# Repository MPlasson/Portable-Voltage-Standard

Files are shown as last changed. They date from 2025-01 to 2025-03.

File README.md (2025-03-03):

# Portable Voltage Standard
A portable voltage reference module, based on the REF7050 chip from Ti.

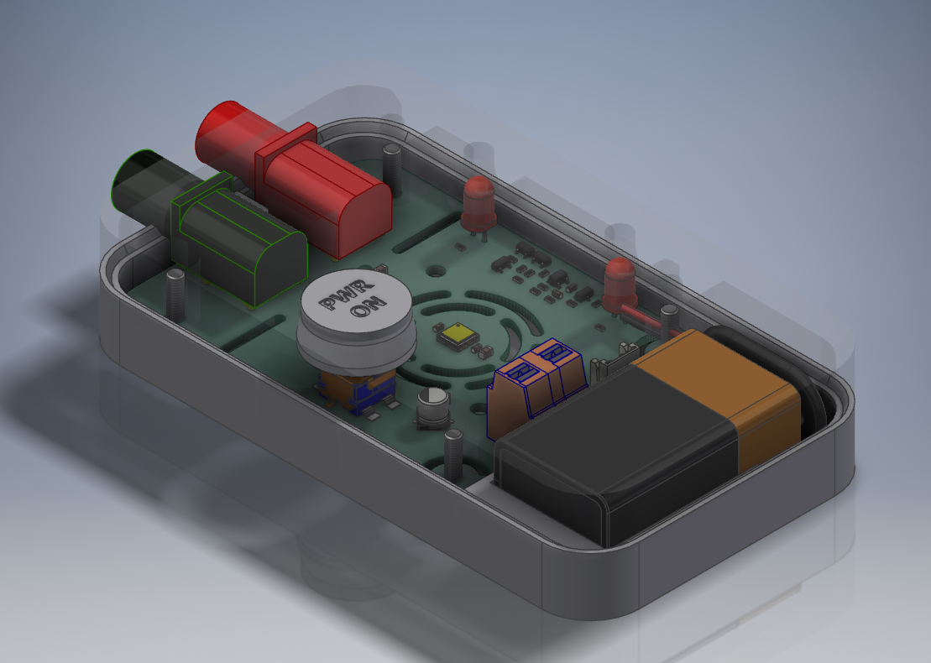
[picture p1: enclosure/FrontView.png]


## Features

- Stable 5V output with high accuracy (< 0.025%)
- Very low temperature coefficient (< 2ppm/°C)
- Battery powered for lowest noise & portability
- Power Good LED indicator
- Low Battery LED indicator

## Tests status

Link to test report: [TestReport](tests/index.md)

- [x] Initial bringup
- [ ] Line regulation
- [ ] Load regulation
- [x] Current consumption
- [ ] Low battery LED trigger voltage
- [x] Ambient temperature accuracy
- [x] Temperature drift [20°C - 50°C]
- [ ] Output stability (100h minimum)

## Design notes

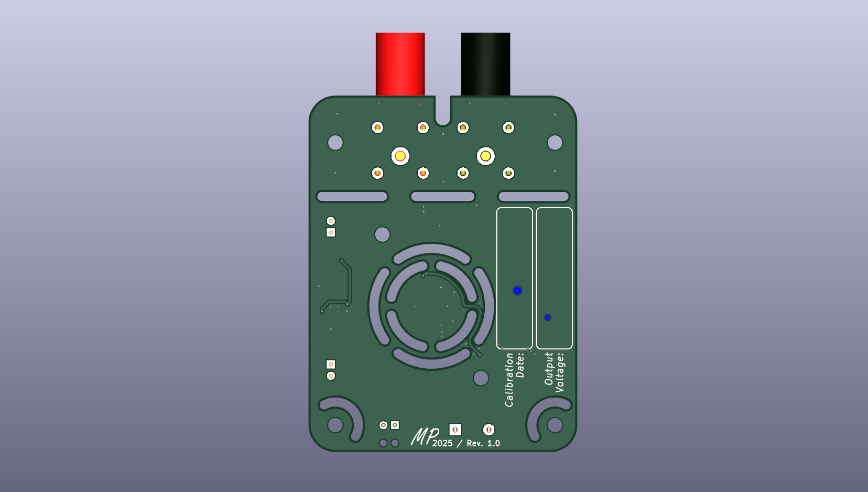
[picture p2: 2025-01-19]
electronics/mainboard/IMG/PortableVoltageStandard_BottomView.png

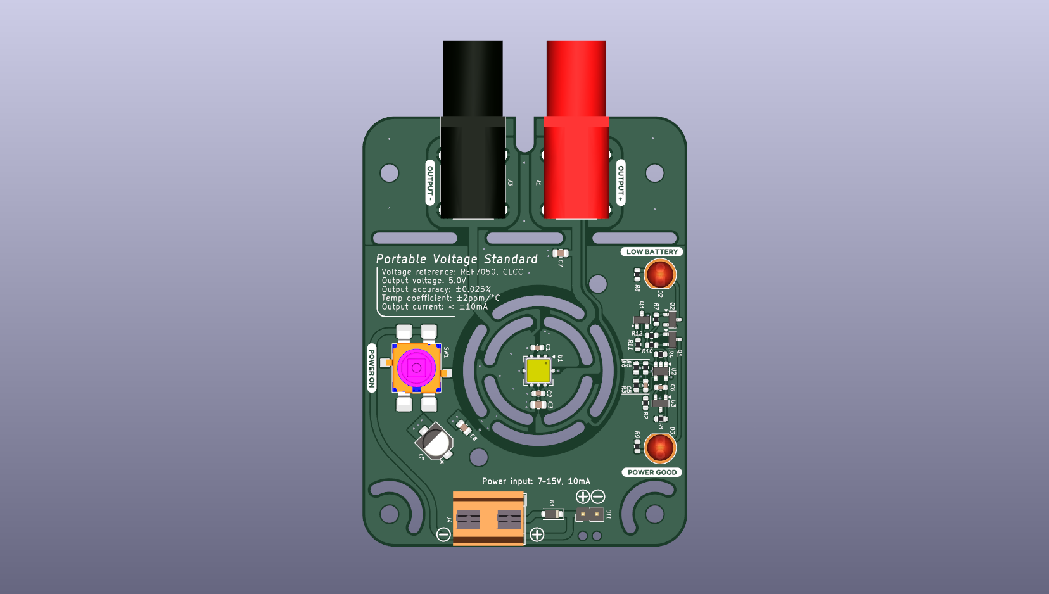
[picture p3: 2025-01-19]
electronics/mainboard/IMG/PortableVoltageStandard_topView.png

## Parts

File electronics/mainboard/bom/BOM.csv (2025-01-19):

Reference | Value | Datasheet | Footprint | Qty | DNP | LCSC
BT1 | 9V_Battery | ~ | Connector_JST:JST_EH_B2B-EH-A_1x02_P2.50mm_Vertical | 1 |  | C3018737
C1,C2,C5,C6 | 100nF | ~ | Capacitor_SMD:C_0603_1608Metric | 4 |  | C14663
C3,C7 | 22uF | ~ | Capacitor_SMD:C_0805_2012Metric | 2 |  | C602037
C4 | 10uF | ~ | Capacitor_SMD:CP_Elec_5x5.3 | 1 |  | C365682
C8 | 1uF | ~ | Capacitor_SMD:C_0805_2012Metric | 1 |  | C28323
D1 | K14 | ~ | Diode_SMD:D_SOD-123F | 1 |  | C908662
D2 | LOW_VOLTAGE | ~ | LED_THT:LED_D5.0mm | 1 |  | C7470717
D3 | POWER_GOOD | ~ | LED_THT:LED_D5.0mm | 1 |  | C7433083
J1 | OUTF | ~ | KICAD_GENERAL_LIBRARY:banana_socket_24.245.1_Amass_rouge | 1 |  | C7437326
J3 | GND | ~ | KICAD_GENERAL_LIBRARY:banana_socket_24.245.2_Amass_noire | 1 |  | C7437327
J4 | AUX_POWER | ~ | TerminalBlock_MetzConnect:TerminalBlock_MetzConnect_Type171_RT13702HBWC_1x02_P7.50mm_Horizontal | 1
Q1,Q2 | AP2302B | https://www.lcsc.com/datasheet/lcsc_datasheet_2411201841_ALLPOWER-ShenZhen-Quan-Li-Semiconductor-AP2302B_C406812.pdf | Package_TO_SOT_SMD:SOT-23 | 2 |  | C406812
Q3 | AP2301B | https://www.lcsc.com/datasheet/lcsc_datasheet_2411201843_ALLPOWER-ShenZhen-Quan-Li-Semiconductor-AP2301B_C2763847.pdf | Package_TO_SOT_SMD:SOT-23 | 1 |  | C2763847
R1 | 33k | ~ | Resistor_SMD:R_0603_1608Metric | 1 |  | C126359
R2 | 470k | ~ | Resistor_SMD:R_0603_1608Metric | 1 |  | C114622
R3 | 100k | ~ | Resistor_SMD:R_0603_1608Metric | 1 |  | C14675
R4,R10 | 1Meg | ~ | Resistor_SMD:R_0603_1608Metric | 2 |  | C105578
R5,R6 | 300k | ~ | Resistor_SMD:R_0603_1608Metric | 2 |  | C114667
R7,R11,R12 | 100 | ~ | Resistor_SMD:R_0603_1608Metric | 3 |  | C105588
R8,R9 | 1k | ~ | Resistor_SMD:R_0603_1608Metric | 2 |  | C22548
SW1 | SW_Push_SPDT | ~ | KICAD_GENERAL_LIBRARY:SPEF210200 | 1 |  | C278409
U1 | REF7050 | https://www.lcsc.com/datasheet/lcsc_datasheet_2309251242_Texas-Instruments-REF7050QFKHT_C6760318.pdf | Package_LCC:Analog_LCC-8_5x5mm_P1.27mm | 1 |  | C6760318
U2 | NCS333 | https://www.onsemi.com/pdf/datasheet/ncs333-d.pdf | Package_TO_SOT_SMD:SOT-23-5 | 1 |  | C74336
U3 | LM4040DBZ-2.5 | http://www.ti.com/lit/ds/symlink/lm4040-n.pdf | Package_TO_SOT_SMD:SOT-23 | 1 |  | C2156989

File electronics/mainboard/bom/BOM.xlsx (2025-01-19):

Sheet: BOM (2)
Reference | Value | Datasheet | Footprint | Qty | DNP | LCSC
BT1 | 9V_Battery | ~ | Connector_JST:JST_EH_B2B-EH-A_1x02_P2.50mm_Vertical | 1 |  | C3018737
 | 9V battery connector |  |  |  |  | C19184111
C1,C2,C5,C6 | 100nF | ~ | Capacitor_SMD:C_0603_1608Metric | 4 |  | C14663
C3,C7 | 22uF | ~ | Capacitor_SMD:C_0805_2012Metric | 2 |  | C602037
C4 | 10uF | ~ | Capacitor_SMD:CP_Elec_5x5.3 | 1 |  | C365682
C8 | 1uF | ~ | Capacitor_SMD:C_0805_2012Metric | 1 |  | C28323
D1 | K14 | ~ | Diode_SMD:D_SOD-123F | 1 |  | C908662
D2 | LOW_VOLTAGE | ~ | LED_THT:LED_D5.0mm | 1 |  | C7470717
D3 | POWER_GOOD | ~ | LED_THT:LED_D5.0mm | 1 |  | C7433083
J1 | OUTF | ~ | KICAD_GENERAL_LIBRARY:banana_socket_24.245.1_Amass_rouge | 1 |  | C7437326
J3 | GND | ~ | KICAD_GENERAL_LIBRARY:banana_socket_24.245.2_Amass_noire | 1 |  | C7437327
J4 | AUX_POWER | ~ | TerminalBlock_MetzConnect:TerminalBlock_MetzConnect_Type171_RT13702HBWC_1x02_P7.50mm_Horizontal | 1
Q1,Q2 | AP2302B | https://www.lcsc.com/datasheet/lcsc_datasheet_2411201841_ALLPOWER-ShenZhen-Quan-Li-Semiconductor-AP2302B_C406812.pdf | Package_TO_SOT_SMD:SOT-23 | 2 |  | C406812
Q3 | AP2301B | https://www.lcsc.com/datasheet/lcsc_datasheet_2411201843_ALLPOWER-ShenZhen-Quan-Li-Semiconductor-AP2301B_C2763847.pdf | Package_TO_SOT_SMD:SOT-23 | 1 |  | C2763847
R1 | 33k | ~ | Resistor_SMD:R_0603_1608Metric | 1 |  | C126359
R2 | 470k | ~ | Resistor_SMD:R_0603_1608Metric | 1 |  | C114622
R3 | 100k | ~ | Resistor_SMD:R_0603_1608Metric | 1 |  | C14675
R4,R10 | 1Meg | ~ | Resistor_SMD:R_0603_1608Metric | 2 |  | C105578
R5,R6 | 300k | ~ | Resistor_SMD:R_0603_1608Metric | 2 |  | C114667
R7,R11,R12 | 100 | ~ | Resistor_SMD:R_0603_1608Metric | 3 |  | C105588
R8,R9 | 1k | ~ | Resistor_SMD:R_0603_1608Metric | 2 |  | C22548
SW1 | SW_Push_SPDT | ~ | KICAD_GENERAL_LIBRARY:SPEF210200 | 1 |  | C278409
U1 | REF7050 | https://www.lcsc.com/datasheet/lcsc_datasheet_2309251242_Texas-Instruments-REF7050QFKHT_C6760318.pdf | Package_LCC:Analog_LCC-8_5x5mm_P1.27mm | 1 |  | C6760318
U2 | NCS333 | https://www.onsemi.com/pdf/datasheet/ncs333-d.pdf | Package_TO_SOT_SMD:SOT-23-5 | 1 |  | C74336
U3 | LM4040DBZ-2.5 | http://www.ti.com/lit/ds/symlink/lm4040-n.pdf | Package_TO_SOT_SMD:SOT-23 | 1 |  | C2156989

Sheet: BOM
Reference | Value | Datasheet | Footprint | Qty | DNP | LCSC
BT1 | 9V_Battery | ~ | Connector_JST:JST_EH_B2B-EH-A_1x02_P2.50mm_Vertical | 1 |  | C3018737
 | 9V battery connector |  |  |  |  | C19184111
C1,C2,C5,C6 | 100nF | ~ | Capacitor_SMD:C_0603_1608Metric | 4 |  | C14663
C3,C7 | 22uF | ~ | Capacitor_SMD:C_0805_2012Metric | 2 |  | C602037
C4 | 10uF | ~ | Capacitor_SMD:CP_Elec_5x5.3 | 1 |  | C365682
C8 | 1uF | ~ | Capacitor_SMD:C_0805_2012Metric | 1 |  | C28323
D1 | K14 | ~ | Diode_SMD:D_SOD-123F | 1
D2 | LOW_VOLTAGE | ~ | LED_THT:LED_D5.0mm | 1
D3 | POWER_GOOD | ~ | LED_THT:LED_D5.0mm | 1
J1 | OUTF | ~ | KICAD_GENERAL_LIBRARY:banana_socket_24.245.1_Amass_rouge | 1
J3 | GND | ~ | KICAD_GENERAL_LIBRARY:banana_socket_24.245.2_Amass_noire | 1
J4 | AUX_POWER | ~ | TerminalBlock_MetzConnect:TerminalBlock_MetzConnect_Type171_RT13702HBWC_1x02_P7.50mm_Horizontal | 1
Q1,Q2 | AO3400A | http://www.aosmd.com/pdfs/datasheet/AO3400A.pdf | Package_TO_SOT_SMD:SOT-23 | 2
Q3 | AO3401A | http://www.aosmd.com/pdfs/datasheet/AO3401A.pdf | Package_TO_SOT_SMD:SOT-23 | 1
R1 | 33k | ~ | Resistor_SMD:R_0603_1608Metric | 1 |  | C126359
R2 | 470k | ~ | Resistor_SMD:R_0603_1608Metric | 1 |  | C114622
R3 | 100k | ~ | Resistor_SMD:R_0603_1608Metric | 1 |  | C14675
R4,R10 | 1Meg | ~ | Resistor_SMD:R_0603_1608Metric | 2 |  | C105578
R5,R6 | 300k | ~ | Resistor_SMD:R_0603_1608Metric | 2 |  | C114667
R7,R11,R12 | 100 | ~ | Resistor_SMD:R_0603_1608Metric | 3 |  | C105588
R8,R9 | 1k | ~ | Resistor_SMD:R_0603_1608Metric | 2 |  | C22548
SW1 | SW_Push_SPDT | ~ | KICAD_GENERAL_LIBRARY:SPEF210200 | 1 |  | C278409
U1 | REF7050 | https://www.lcsc.com/datasheet/lcsc_datasheet_2309251242_Texas-Instruments-REF7050QFKHT_C6760318.pdf | Package_LCC:Analog_LCC-8_5x5mm_P1.27mm | 1 |  | C6760318
U2 | NCS333 | https://www.onsemi.com/pdf/datasheet/ncs333-d.pdf | Package_TO_SOT_SMD:SOT-23-5 | 1
U3 | LM4040DBZ-2.5 | http://www.ti.com/lit/ds/symlink/lm4040-n.pdf | Package_TO_SOT_SMD:SOT-23 | 1

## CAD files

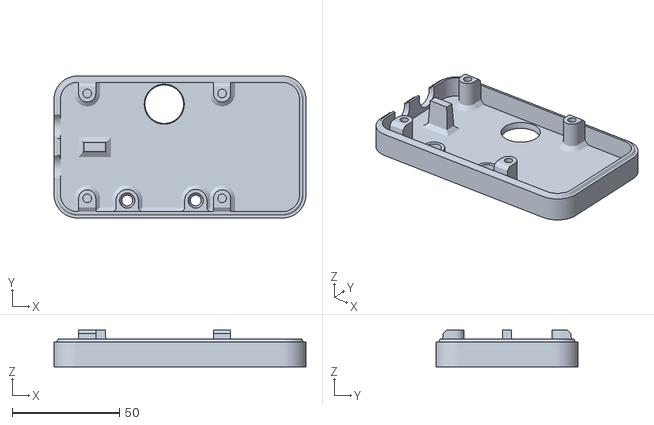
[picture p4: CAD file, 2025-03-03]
enclosure/Case_Top.stl
117.7 x 66.4 x 17.1

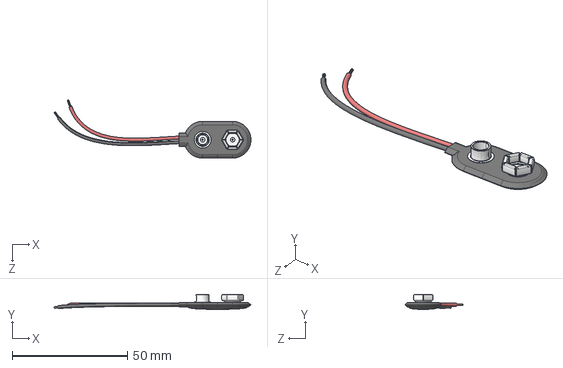
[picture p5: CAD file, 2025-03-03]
enclosure/9V Battery Clip Connector.STEP
85.5 x 6.40 x 25.3 mm

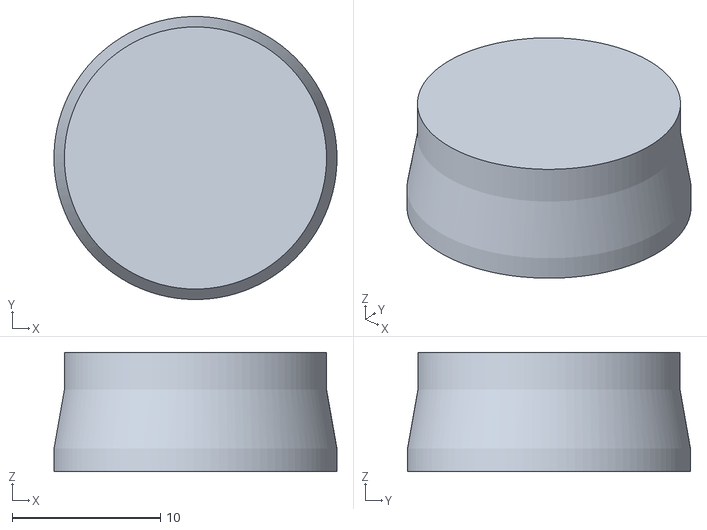
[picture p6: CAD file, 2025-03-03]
enclosure/Power_Button.stl
19.1 x 19.1 x 8.05

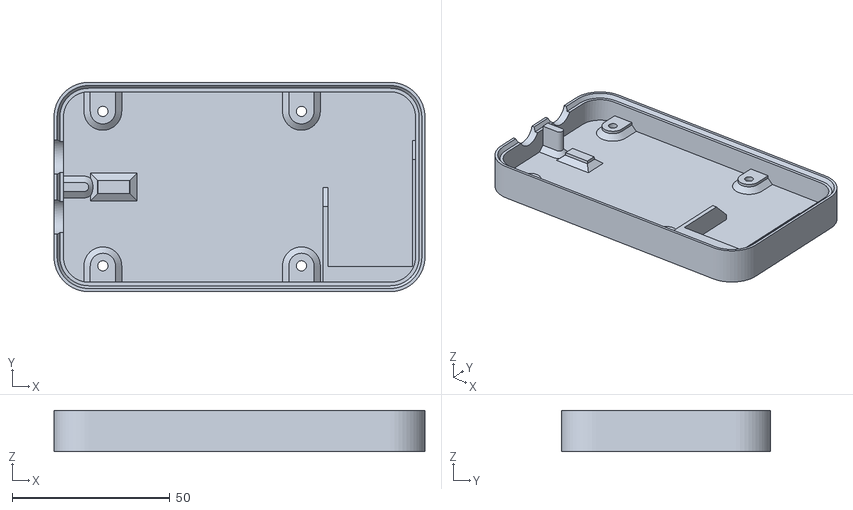
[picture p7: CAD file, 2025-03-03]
enclosure/Case_Bottom.stl
117.7 x 66.4 x 13.1

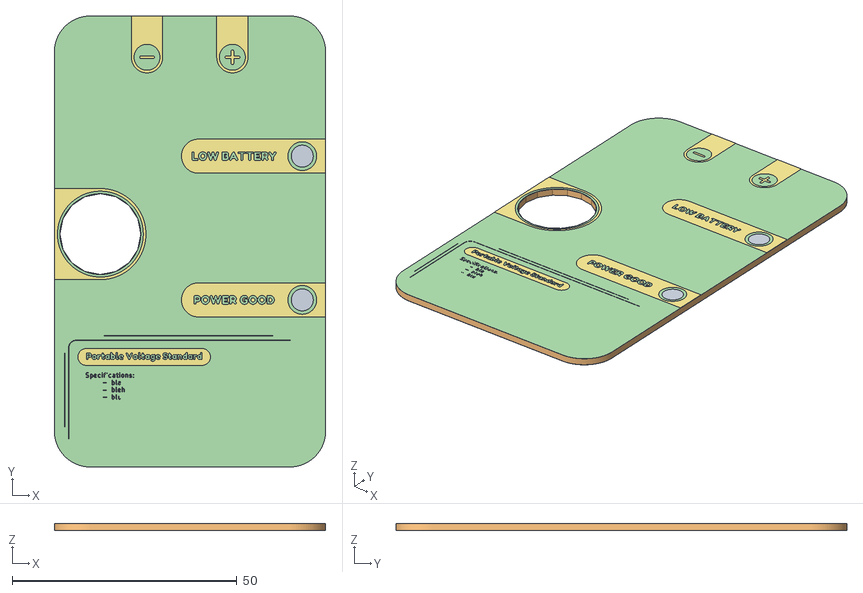
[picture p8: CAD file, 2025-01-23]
enclosure/PVS_FrontPanel.obj
60.4 x 100.4 x 1.69

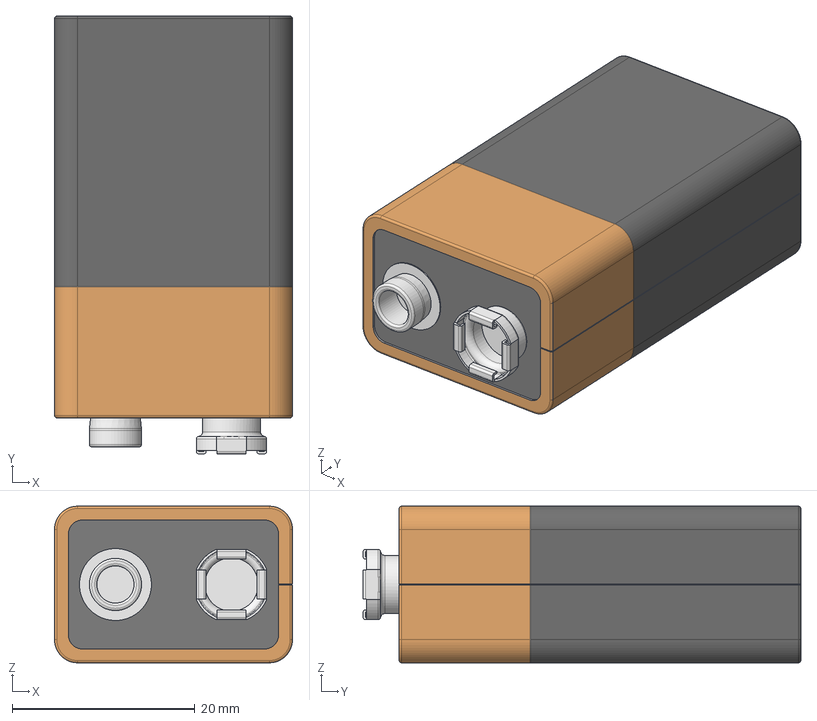
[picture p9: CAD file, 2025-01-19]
enclosure/9V-battery.stp
26.0 x 47.9 x 17.1 mm

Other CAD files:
enclosure/9V Battery Clip Connector.ipt
enclosure/Case_Bottom.ipt
enclosure/Case_Top.ipt
enclosure/FrontPanelBezel.ipt
enclosure/OldVersions/9V Battery Clip Connector.0001.ipt
enclosure/OldVersions/Case_Bottom.0048.ipt
enclosure/OldVersions/Case_Top.0072.ipt
enclosure/OldVersions/PortableVoltageStandard_Assembly.0071.iam
enclosure/OldVersions/Power_Button.0035.ipt
enclosure/PVS_FrontPanel.ipt
enclosure/PortableVoltageStandard_Assembly.iam
enclosure/Power_Button.ipt

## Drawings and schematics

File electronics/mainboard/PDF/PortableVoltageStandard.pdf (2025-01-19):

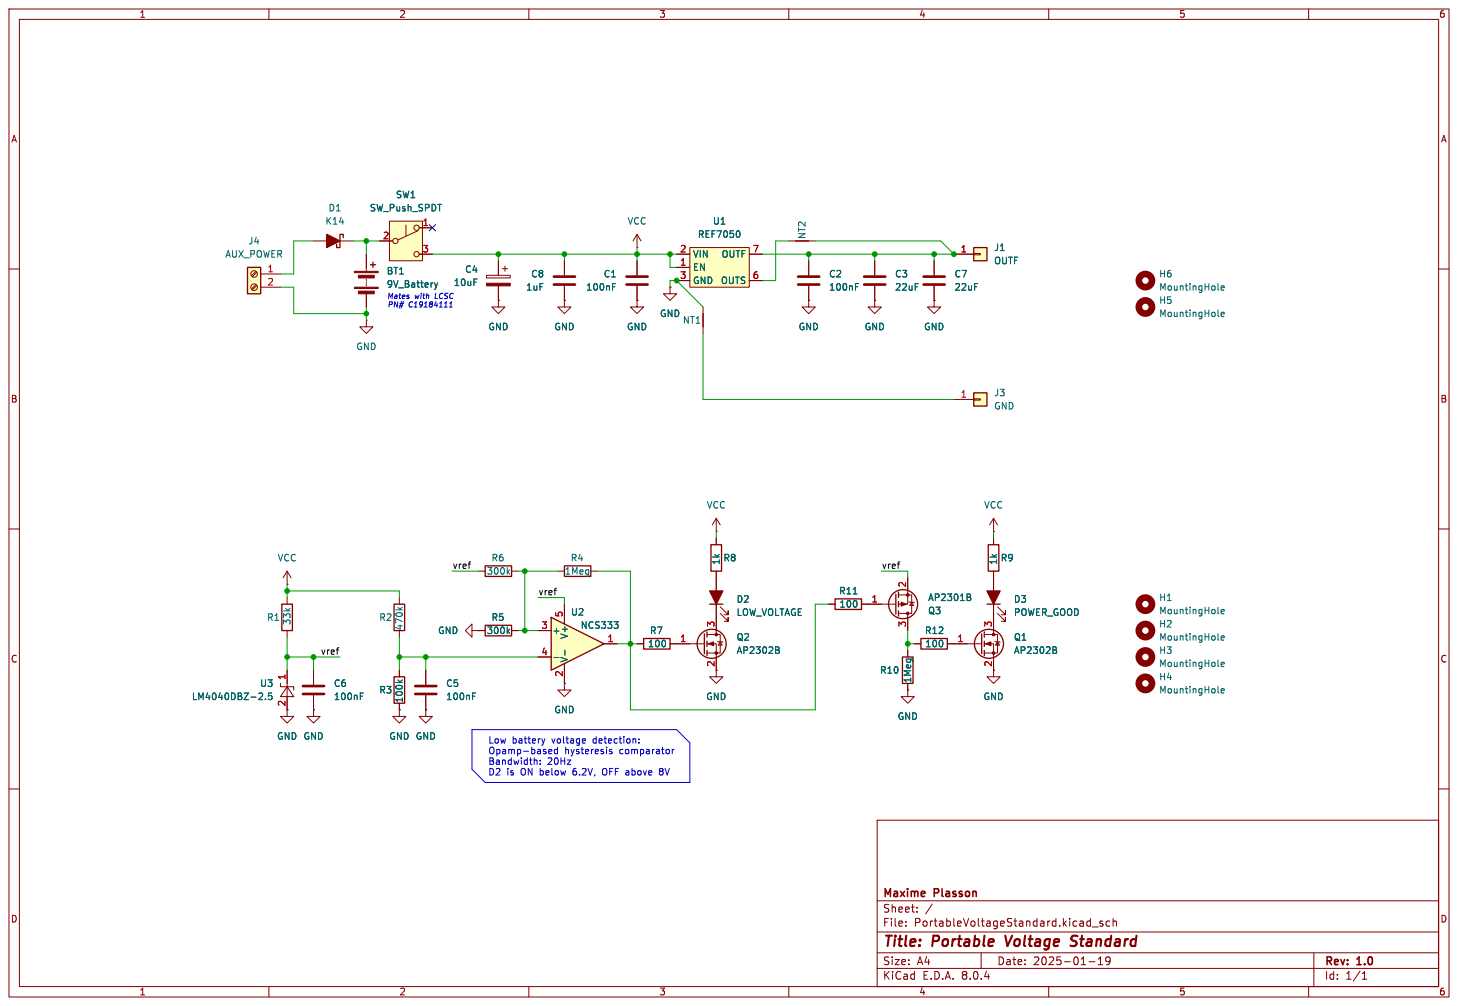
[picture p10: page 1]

1 2 U1 REF7050 EN 1 VIN 2 GND 3 OUTS 6 OUTF 7 J1OUTF

Id: 1/1 Title: Portable Voltage Standard

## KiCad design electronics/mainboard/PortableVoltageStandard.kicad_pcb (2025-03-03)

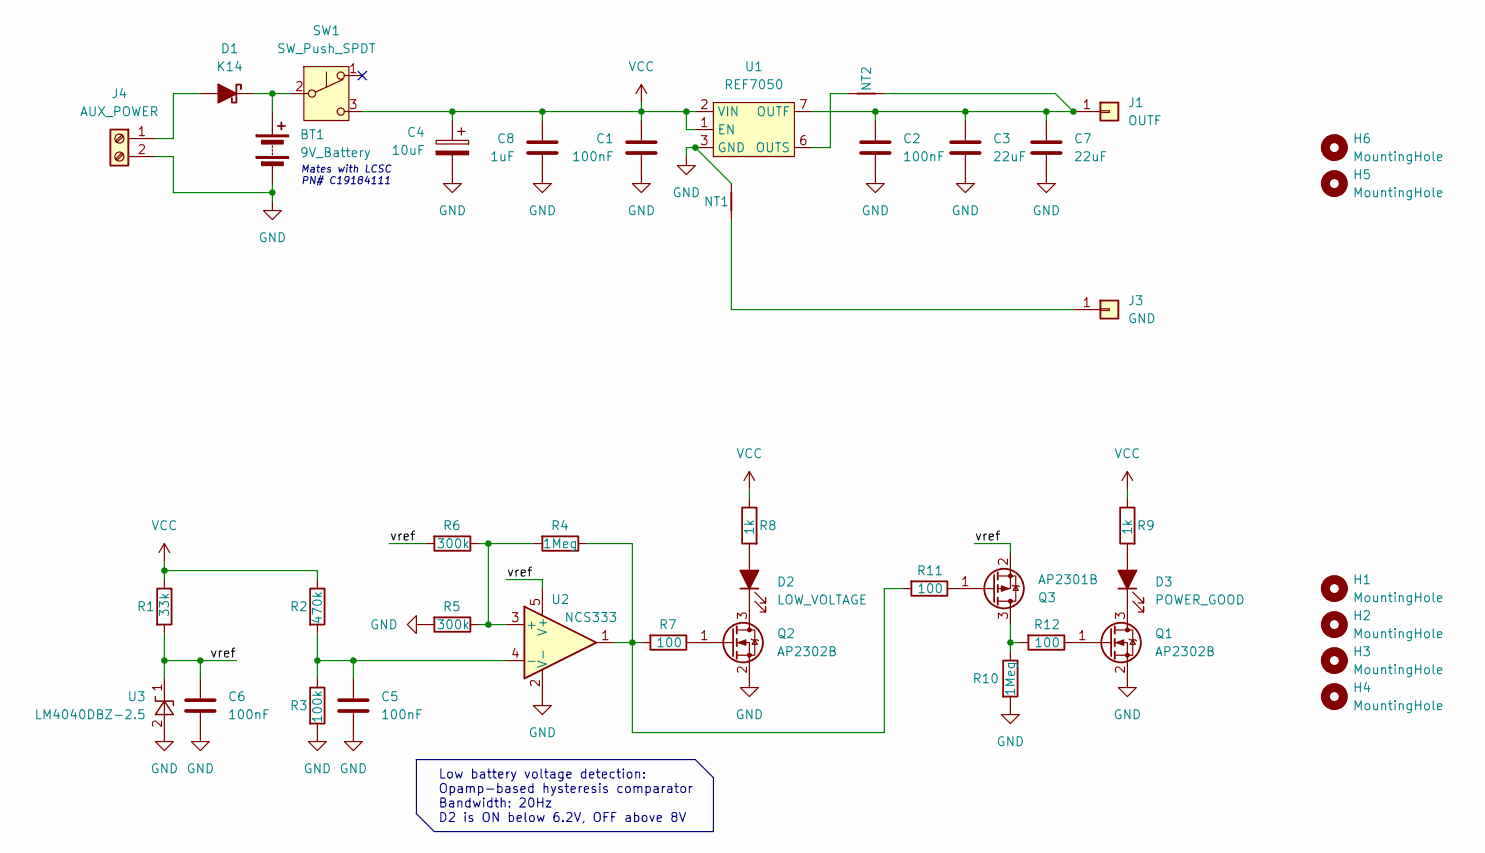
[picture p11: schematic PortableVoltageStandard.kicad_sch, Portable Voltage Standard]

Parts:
BT1: 9V_Battery; JST_EH_B2B-EH-A_1x02_P2.50mm_Vertical; LCSC C3018737
C1, C2, C5, C6: 100nF; C_0603_1608Metric; LCSC C14663
C3, C7: 22uF; C_0805_2012Metric; LCSC C602037
C4: 10uF; CP_Elec_5x5.3; LCSC C365682
C8: 1uF; C_0805_2012Metric; LCSC C28323
D1: K14; D_SOD-123F; LCSC C908662
D2: LOW_VOLTAGE; LED_D5.0mm; LCSC C7470717
D3: POWER_GOOD; LED_D5.0mm; LCSC C7433083
H1, H2, H3, H4, H5, H6: MountingHole; MountingHole_3.2mm_M3
J1: OUTF; banana_socket_24.245.1_Amass_rouge; LCSC C7437326
J3: GND; banana_socket_24.245.2_Amass_noire; LCSC C7437327
J4: AUX_POWER; TerminalBlock_MetzConnect_Type171_RT13702HBWC_1x02_P7.50mm_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
NT1, NT2: NetTie_2; NetTie-2_SMD_Pad0.5mm
Q1, Q2: AP2302B; SOT-23; LCSC C406812
Q3: AP2301B; SOT-23; LCSC C2763847
R1: 33k; R_0603_1608Metric; LCSC C126359
R2: 470k; R_0603_1608Metric; LCSC C114622
R3: 100k; R_0603_1608Metric; LCSC C14675
R4, R10: 1Meg; R_0603_1608Metric; LCSC C105578
R5, R6: 300k; R_0603_1608Metric; LCSC C114667
R7, R11, R12: 100; R_0603_1608Metric; LCSC C105588
R8, R9: 1k; R_0603_1608Metric; LCSC C22548
SW1: SW_Push_SPDT; SPEF210200; LCSC C278409
U1: REF7050; Analog_LCC-8_5x5mm_P1.27mm; LCSC C6760318
U2: NCS333; SOT-23-5; LCSC C74336
U3: LM4040DBZ-2.5; SOT-23; LCSC C2156989

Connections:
/vref: C6.1, Q3.2 (S), R1.2, R6.2, U2.5 (V+), U3.1 (K)
GND: BT1.2 (-), C1.2, C2.2, C3.2, C4.2, C5.2, C6.2, C7.2, C8.2, J4.2, NT1.2, Q1.2 (S), Q2.2 (S), R3.2, R5.2, R10.2, U1.3 (GND), U1.4 (GND), U1.5 (GND), U1.8 (GND), U2.2 (V-), U3.2 (A)
unnamed: BT1.1 (+), D1.1 (K), SW1.2 (B)
unnamed: D1.2 (A), J4.1
unnamed: D2.2 (A), R8.2
unnamed: D2.1 (K), Q2.3 (D)
unnamed: D3.2 (A), R9.2
unnamed: D3.1 (K), Q1.3 (D)
unnamed: C2.1, C3.1, C7.1, J1.1, NT2.2, U1.7 (OUTF)
unnamed: J3.1, NT1.1
unnamed: Q1.1 (G), R12.1
unnamed: Q2.1 (G), R7.1
unnamed: Q3.3 (D), R10.1, R12.2
unnamed: Q3.1 (G), R11.1
unnamed: R4.1, R7.2, R11.2, U2.1
unnamed: NT2.1, U1.6 (OUTS)
unnamed: R4.2, R5.1, R6.1, U2.3 (+)
unnamed: C5.1, R2.2, R3.1, U2.4 (-)
VCC: C1.1, C4.1, C8.1, R1.1, R2.1, R8.1, R9.1, SW1.3 (C), U1.1 (EN), U1.2 (VIN)

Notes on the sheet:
Low battery voltage detection: Opamp-based hysteresis comparator Bandwidth: 20Hz D2 is ON below 6.2V, OFF above 8V
Mates with LCSC PN# C19184111

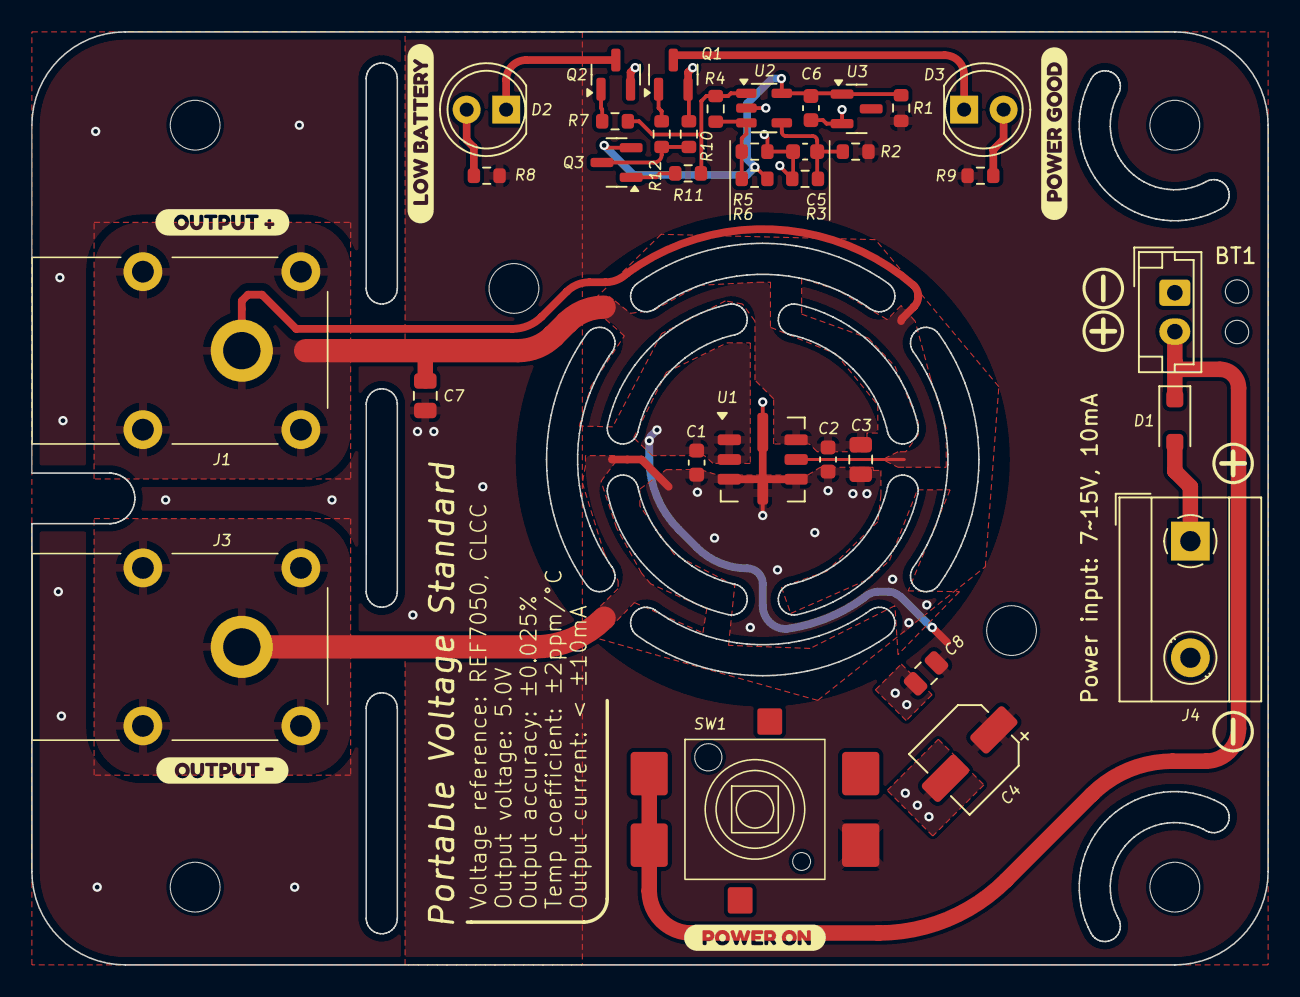
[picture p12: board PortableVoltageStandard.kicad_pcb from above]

Board: 2 copper layers, 79.5 x 60.0 mm, 49 parts (0 on the bottom side), 19 nets.

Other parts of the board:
H3#2, H3#3: MountingHole; MountingHole_3.2mm_M3
kibuzzard-678D0B69: G***; kibuzzard-678D0B69
kibuzzard-678D07AC: G***; kibuzzard-678D07AC
kibuzzard-678D073D: G***; kibuzzard-678D073D
kibuzzard-678D0758: G***; kibuzzard-678D0758
kibuzzard-678D0795: G***; kibuzzard-678D0795

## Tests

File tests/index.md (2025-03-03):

# Portable Voltage Standard: Tests results

## Line regulation
Not done yet :/

## Load regulation
Not done yet :/

## Current consumption
When using the alternate power input (through the push-in connector) the board draws around 11mA, which is reasonable.

This should give us an approximate battery life of 500h (considering a typical 9V battery with a cutoff voltage of 6V).

## Low battery LED trigger voltage
Not done yet :/

## Ambient temperature accuracy

At ambient temperature (~21°C) the output voltage is close to 4.99982V, which corresponds to an error of around 36ppm. Not bad for a ±0.025% (250ppm) chip !

## Temperature drift [20°C - 50°C]
The PVS was put in a small thermal chamber and the temperature was set to around 55°C.
Both the output voltage and the ambient temperature were recorded (respectively with a DMM6500 and a class A PT100 RTD)

The temperature & output voltage profile is in the figure below:
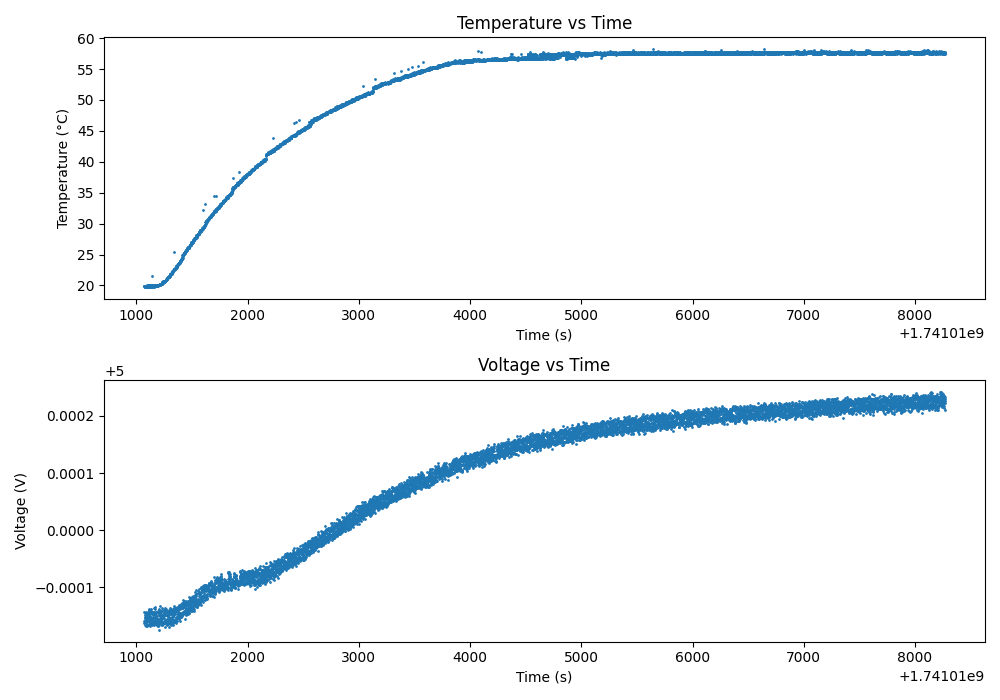
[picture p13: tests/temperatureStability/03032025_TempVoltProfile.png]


By plotting output voltage deviation (relative to a perfect 5V) relative to he temperature, we get the following picture:
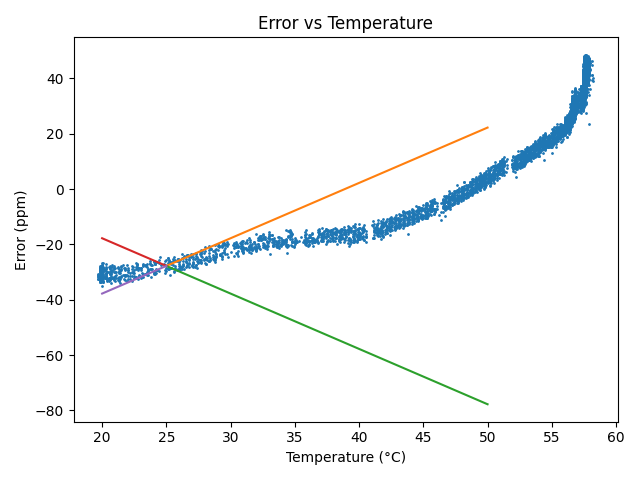
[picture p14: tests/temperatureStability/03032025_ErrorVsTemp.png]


Each line beginning at 25°C has a slope of ±2ppm/°C, which corresponds to the Ti specification. Out prototype is inside the limits for common lab temperatures.
## Output stability (100h minimum)
Not done yet :/

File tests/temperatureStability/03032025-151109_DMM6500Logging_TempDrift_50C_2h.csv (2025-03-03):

TestName=TempDrift_50C_2h
DurationSeconds=7200
SamplingPeriodSeconds=1
timestamp | voltage | temperature
1741011069.7050157 | 4.9998404671 | 19.9
1741011070.6812496 | 4.9998374733 | 19.9
1741011071.6794908 | 4.9998564053 | 19.9
1741011072.6816766 | 4.9998430031 | 19.9
1741011073.6828022 | 4.9998395407 | 19.9
1741011074.6821513 | 4.9998548772 | 19.9
1741011075.6820543 | 4.9998343209 | 19.8
1741011076.6880102 | 4.99985124 | 19.8
1741011077.6914966 | 4.999845616 | 19.9
1741011078.6881206 | 4.9998411857 | 19.8
1741011079.682427 | 4.9998471576 | 19.8
1741011080.679677 | 4.9998411844 | 19.9
1741011081.678088 | 4.9998563843 | 19.8
1741011082.6766026 | 4.999838144 | 19.7
1741011083.674513 | 4.9998539457 | 19.8
1741011084.672267 | 4.9998325678 | 19.8
1741011085.6775978 | 4.9998515164 | 19.9
1741011086.6728673 | 4.9998434158 | 19.9
1741011087.670144 | 4.9998511665 | 19.8
1741011088.6714807 | 4.9998374638 | 19.7
1741011089.6723115 | 4.9998380989 | 19.9
1741011090.669593 | 4.999839848 | 19.8
1741011091.66842 | 4.9998404786 | 19.8
1741011092.663858 | 4.9998477665 | 20
1741011093.668227 | 4.9998316942 | 19.9
1741011094.6681426 | 4.9998545484 | 19.9
1741011095.6669707 | 4.9998339646 | 19.9
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

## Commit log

2025-01-19 Added zip file for gerbers
2025-01-19 HW finishing & mechanical beginning
    Final modifications to the hardware side:
    - BOM updated
    - LCSC PN added to sch/bom
    Initial work on mechanical enclosure:
    - Bottom & top case started
    - Power button added
    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
    [9V-battery.stp, BOM.csv, BOM.xlsx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]
2025-01-19 Added mechanical step files
    Added large STEP files
    [9V-battery.stp]
2025-01-19 Updated folder names to be more explicit
    [9V-battery.stp, BOM.csv, BOM.xlsx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]
2025-01-21 Front panel work
    Initial work on front panel design (kicad project creation)
    Added more sub folders to /electronics
    Encosure: changed the push button knob to a diameter of 18mm for ease of use
    [BOM.csv, BOM.xlsx, Case_Top.0043.ipt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]
2025-01-22 Mech update
    Created front panel bezel
    Added screws to assembly
    Updated the screw length for more grip
    [Case_Bottom.0020.ipt, Case_Bottom.0021.ipt, Case_Bottom.ipt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]
2025-01-23 Update to the enclosure
    Modified screw type: M3 machine screws, with metal threaded inserts
    [Case_Bottom.0021.ipt, Case_Bottom.0023.ipt, Case_Bottom.ipt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]
2025-01-23 Front panel improvement
    Began working on the front panel design
    Added to mech assembly
    [PVS_FrontPanel.ipt, PVS_FrontPanel.kicad_pcb, PVS_FrontPanel.obj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]
2025-02-09 Enclosure changes
    Added lips to all mating parts
    New design for power button: soft press fit into the pushbutton
    [Case_Bottom.0023.ipt, Case_Bottom.0028.ipt, Case_Bottom.ipt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]
2025-02-09 STL export for first 3D print
    [Case_Bottom.0028.ipt, Case_Bottom.0029.ipt, Case_Bottom.ipt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]
2025-03-03 Enclosure update
    Rotated the9V battery to a a thinner enclosure & be able to cable manage the inside
    Fixed misalignment between banana jacks & enclosure
    [03032025-151109_DMM6500Logging_TempDrift_50C_2h.csv, 9V Battery Clip Connector.0001.ipt, 9V Battery Clip Connector.STEP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]
